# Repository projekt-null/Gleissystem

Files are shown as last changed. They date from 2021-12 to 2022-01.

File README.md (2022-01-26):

# Projekt-Null Spur 0 Gleise

Dieses GitHub Repository enthält Konstruktionsdateien zum Selbstbau von Spur 0 Gleismaterial. Die Konstruktionsdateien liegen sowohl im Ausgangsformat Autodesk Fusion 360 vor, als auch in diversen Exporten, um zum Beispiel Bauteile im Laserverfahren zu schneiden oder 3D zu drucken.

Weiterführende Informationen zu diesem Projekt sind der Projekt Null Homepage zu entnehmen: [Projekt Null Spur 0 Gleise](https://projekt-null.de/projekte/spur-0-gleise/einfuehrung/)

## Inhalt

- Regelspur_Gleise - Enthält Einzelschwellen oder Schwellenbänder für die Nachbildung von Holzschwellen im Modell
- Regelspur_Schablonen - Enthält Schablonen zum sauberen Verlegen von Einzelschwellen 

## Pushen von Änderungen

Zum heutigen Standpunkt ist noch unklar wie Änderungen, durch die Contributoren, ordentlich in das Repository übernommen werden können. Daher die Bitte, fügt den veränderten Dateien einen Suffix in Form von _vNNN_KKK hinzu. NNN steht dabei für eine laufende Versionsnummer und KKK für euer Namenskürzel. Sobald ihr dem Projekt beitritt, erhält ihr ein eindeutiges Namenskürzel.  

## Lizenzierung

Das Open Source Projekt *Projekt-Null Spur 0 Gleise* steht unter der LGLPv3 Lizenz. 

Über die bereitgestellten Konstruktionsdaten kann frei verfügt werden. Bei Vervielfältigung und kommerziellen Gebrauch, gilt es allerdings die Lizenzbedingungen einzuhalten. 

Mehr zur LGPLv3 Lizenz: https://www.gnu.org/licenses/lgpl-3.0.de.html

Alternativ wendet euch bei Fragen per E-Mail an: info@projekt-null.de

Ausgeschlossen von den Lizenzbedingungen

- alle Produkte vom Hersteller Hassler-Profile, Oberbühl 111, FL- 9487 Gamprin
- und das K-Modul-System.

Diese Liste gilt es allerdings zu aktualisieren, sobald weitere Produkte von Dritten in die Entwicklungen einfließen.

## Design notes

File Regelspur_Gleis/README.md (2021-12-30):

# Regelspur Gleis

Enthalten sind Konstruktionsdateien für Spur 0 Holzschwellen in Verbindung mit dem K-Modul-System Rippenplatten und den Abmessungen 58x5,8mm (entspr. der 2,6 Meter Schwelle). Die Abmessungen sind identisch mit den Holzschwellen von Michael Weinert und Hegob (Nachbildung in Kunstoff). Die Autodesk Fusion 360 Datei ist vollständig über Parameter veränderbar.

> **Achtung**: Die Schwellenbreite in den Zeichnungen beträgt aktuell 5,75mm, da beim Lasern die Breite größer als 5,8mm ausgefallen ist.

Die Laser-Cut Export stehen in zwei Ausführungen zur Verfügung:
- für Hegob Code 125 Schienenprofile
- für Hassler 3,5mm Schienenprofile

Durch die unterschiedlichen Breiten der Schienenprofile (Kopf und Fuß), muss die K-Modul-System Rippenplatte entsprechend positioniert werden, um die Spurweite von mind. 32mm exakt einzuhalten. In den Parametern wurde den Kopfbreiten sogar etwas Breite (0,05mm) hinzugegeben, was die Spurweite etwas vergrößert.

Hegob Schienenprofile sitzen allerdings nicht ganz so stramm in der K-Modul-System Rippenplatte, wie Hassler oder Peco Code 143 Schienenprofile. Für vorbildlichen Oberbau mit S49 Schienen (also Hegob Code 125) ist das System von Michael Weinert geeigneter.

Geeignetes Material für die Holzschwellen sind 3mm Eichen- oder Lindenvollholzplatten.

> **Achtung**: Das Schwellenband enthält unnötige Verfahrwege beim Laser-Cut. Eine verbesserte Variante befindet sich bereits in Arbeit.

## Inhalt
- 0_Schwellenband_Holz_K_Modul_System_v2.f3d - Autodesk Fusion 360 Konstruktionsdatei, über Parameter veränderbar
- 0_Schwellenband_Holz_K_Modul_System_v2.step - STEP Datei zum Importieren in andere 3D-Konstruktionsprogramme
- 0_Schwellenband_Holz_K_Modul_System_v2__Hegob_Laser_Cut_Kerf_0_15 - Export im DXF-Format zum Laserschneiden mit Schnittweite (Kerf-Width) von 0,15mm für Hegob Code 125 Schienenprofil
- 0_Schwellenband_Holz_K_Modul_System_v2__Hegob_Laser_Cut_Kerf_0_10 - Export im DXF-Format zum Laserschneiden mit Schnittweite (Kerf-Width) von 0,10mm für Hegob Code 125 Schienenprofil
- 0_Einzelschwelle_Holz_K_Modul_System_v2__Hegob_Laser_Cut_Kerf_0_15 - Export im DXF-Format zum Laserschneiden mit Schnittweite (Kerf-Width) von 0,15mm für Hegob Code 125 Schienenprofil
- 0_Einzelschwelle_Holz_K_Modul_System_v2__Hegob_Laser_Cut_Kerf_0_10 - Export im DXF-Format zum Laserschneiden mit Schnittweite (Kerf-Width) von 0,10mm für Hegob Code 125 Schienenprofil
- 0_Schwellenband_Holz_K_Modul_System_v2__Hassler_Laser_Cut_Kerf_0_15 - Export im DXF-Format zum Laserschneiden mit Schnittweite (Kerf-Width) von 0,15mm für Hassler 3,5mm Schienenprofil
- 0_Schwellenband_Holz_K_Modul_System_v2__Hassler_Laser_Cut_Kerf_0_10 - Export im DXF-Format zum Laserschneiden mit Schnittweite (Kerf-Width) von 0,10mm für Hassler 3,5mm Schienenprofil
- 0_Einzelschwelle_Holz_K_Modul_System_v2__Hassler_Laser_Cut_Kerf_0_15 - Export im DXF-Format zum Laserschneiden mit Schnittweite (Kerf-Width) von 0,15mm für Hassler 3,5mm Schienenprofil
- 0_Einzelschwelle_Holz_K_Modul_System_v2__Hassler_Laser_Cut_Kerf_0_10 - Export im DXF-Format zum Laserschneiden mit Schnittweite (Kerf-Width) von 0,10mm für Hassler 3,5mm Schienenprofil

## Offene Punkte

- Unterstützung for Peco Code 143 Schienenprofil hinzufügen
- Laser-Cut Verfahrwege optimieren
- CNC Fräsdatei mit Angabe des Fräserdurchmessers hinzufügen (max. 1,5mm!)

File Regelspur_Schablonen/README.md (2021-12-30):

# Regelspur Schablonen

Enthalten sind Konstruktionsdateien für Schablonen zum Verlegen von Spur 0 Einzelschwellen (58x5,8mm) gemäß Eisenbahner Richtlinien, akuell

- 15m Joche mit Schwelleneinteilung nach DRG-Richtlinie

Geeignetes Material zum Laserschneiden sind 1mm Finnpappe oder MDF.

Die Schablonen können wahlweise auf dem Trassen-/Schotterbett verbleiben oder werden wieder entnommen. Die Schablonen können auch mehrfach verwendet werden. 

Laut FREMO Spur 0 Norm, lautet die aktuelle Trassen-/Schotterbreite 68mm.

## Inhalt

- 0_15m_Joch_Gerade_Schablone_v7.f3d - Autodesk Fusion 360 Konstruktionsdatei, über Parameter veränderbar, u.a. Trassen-/Schotterbett-Breite
- 0_15m_Joch_Gerade_Schablone_v7.step - STEP Datei zum Importieren in andere 3D-Konstruktionsprogramme
- 0_15m_Joch_Gerade_Schablone_v7__Laser_Cut_Kerf_0_10.dxf - Export im DXF-Format zum Laserschneiden mit Schnittweite (Kerf-Width) von 0,10mm
- 0_15m_Joch_Gerade_Schablone_v7__Laser_Cut_Kerf_0_15.dxf - Export im DXF-Format zum Laserschneiden mit Schnittweite (Kerf-Width) von 0,15mm
- 0_15m_Joch_Gebogene_Schablone_v8.f3d - Autodesk Fusion 360 Konstruktionsdatei, über Parameter veränderbar, u.a. Trassen-/Schotterbett-Breite und Bogen-Radius
- 0_15m_Joch_Gebogene_Schablone_v8.step - STEP Datei zum Importieren in andere 3D-Konstruktionsprogramme
- 0_15m_Joch_Gebogene_Schablone_v8__R2500mm_Laser_Cut_Kerf_0_10.dxf - Export im DXF-Format zum Laserschneiden mit Radius 2500mm und Schnittweite (Kerf-Width) von 0,10mm
- 0_15m_Joch_Gebogene_Schablone_v8__R2500mm_Laser_Cut_Kerf_0_15.dxf - Export im DXF-Format zum Laserschneiden mit Radius 2500mm und Schnittweite (Kerf-Width) von 0,15mm
- 0_15m_Joch_Gebogene_Schablone_v8__Lenz_R10_Laser_Cut_Kerf_0_10.dxf - Export im DXF-Format zum Laserschneiden mit Radius Lenz R10 (1649,39mm) und Schnittweite (Kerf-Width) von 0,10mm
- 0_15m_Joch_Gebogene_Schablone_v8__Lenz_R10_Laser_Cut_Kerf_0_15.dxf - Export im DXF-Format zum Laserschneiden mit Radius Lenz R10 (1649,39mm) und Schnittweite (Kerf-Width) von 0,15mm

## Offene Punkte

- 30m Joche gemäß DRG-Richtlinien
- 30m Joche gemäß späterer DB Vorgaben
- Laser Cut Exporte mit weiteren Bogen Radien, zum Beispiel 4000mm, 4222mm, etc.
- Trennstelle zwischen den Schnwellen hinzufügen, damit die Schablone bei einmalige Verwendung, nach links und rechts rausgezogen werden.

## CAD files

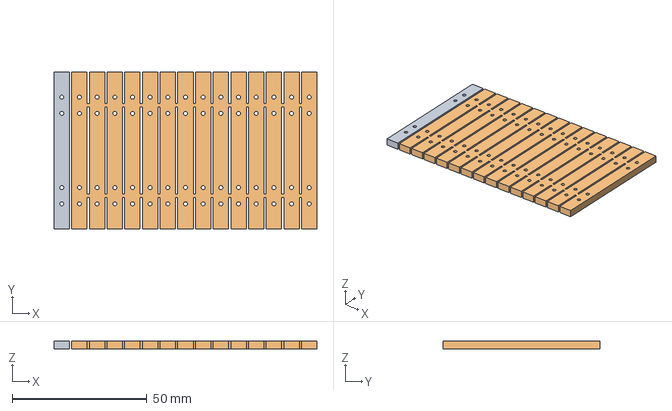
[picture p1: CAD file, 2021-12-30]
Regelspur_Gleis/0_Schwellenband_Holz_K_Modul_System_v2.step
97.5 x 58.0 x 3.00 mm

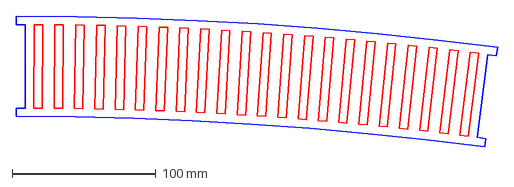
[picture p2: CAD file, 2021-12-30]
Regelspur_Schablonen/0_15m_Joch_Gebogen_Schablone_v8__R2500mm_Laser_Cut_Kerf_0_15.dxf
334.3 x 90.8 mm

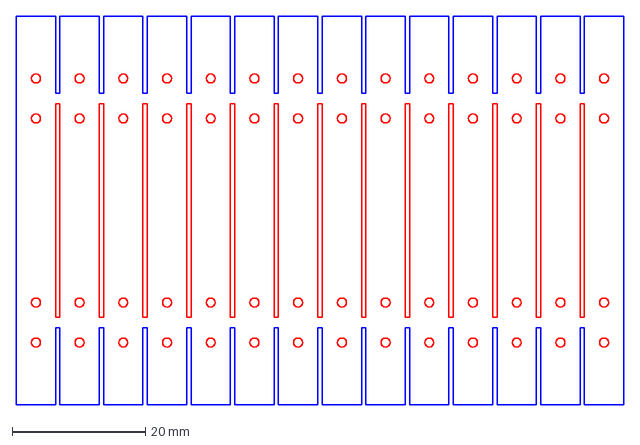
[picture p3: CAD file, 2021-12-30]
Regelspur_Gleis/0_Schwellenband_Holz_K_Modul_System_v2__Hassler_Laser_Cut_Kerf_0_15.dxf
91.1 x 58.2 mm

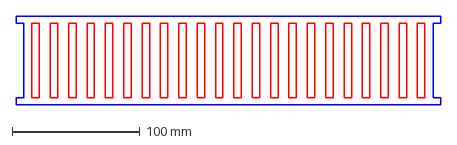
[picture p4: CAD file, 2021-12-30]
Regelspur_Schablonen/0_15m_Joch_Gerade_Schablone_v7__Laser_Cut_Kerf_0_15.dxf
332.8 x 69.7 mm

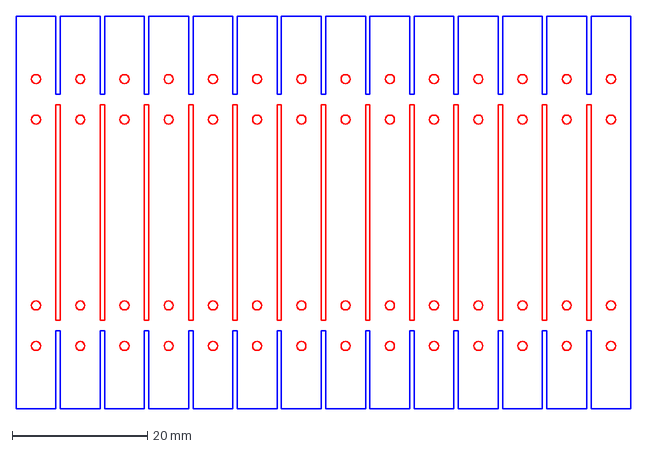
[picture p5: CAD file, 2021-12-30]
Regelspur_Gleis/0_Schwellenband_Holz_K_Modul_System_v2__Hegob_Laser_Cut_Kerf_0_15.dxf
91.1 x 58.2 mm

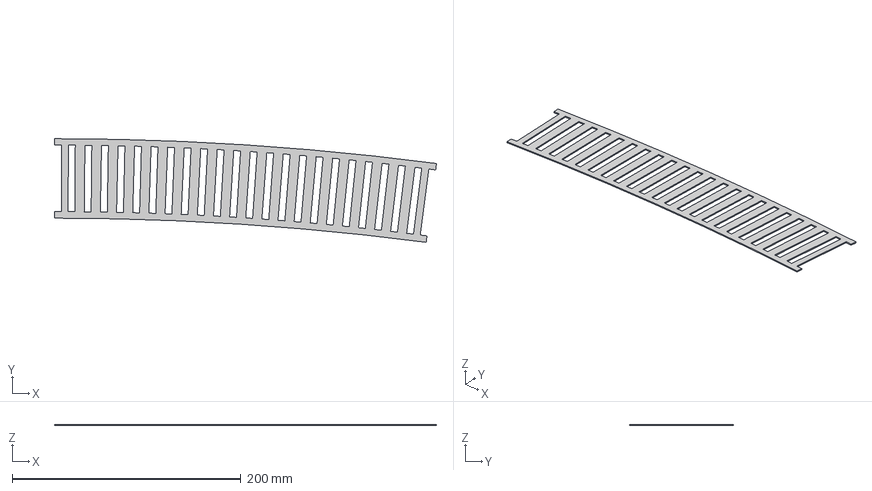
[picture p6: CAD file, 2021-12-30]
Regelspur_Schablonen/0_15m_Joch_Gebogen_Schablone_v8.step
334.2 x 90.7 x 1.00 mm

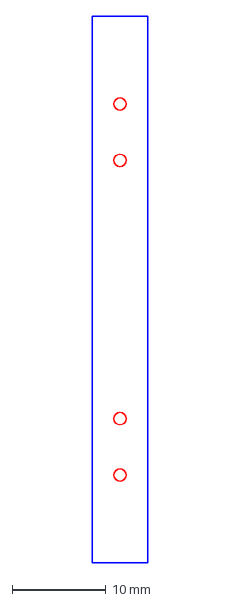
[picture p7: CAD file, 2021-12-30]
Regelspur_Gleis/0_Einzelschwelle_Holz_K_Modul_System_v2__Hegob_Laser_Cut_Kerf_0_15.dxf
5.90 x 58.2 mm

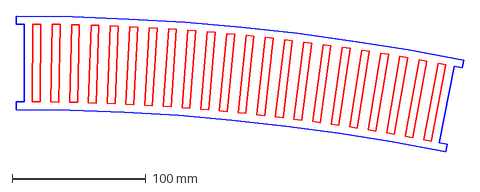
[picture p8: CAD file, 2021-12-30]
Regelspur_Schablonen/0_15m_Joch_Gebogen_Schablone_v8__Lenz_R10_Laser_Cut_Kerf_0_15.dxf
334.4 x 101.3 mm

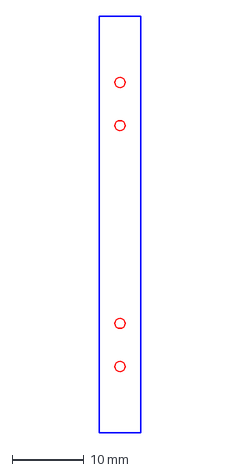
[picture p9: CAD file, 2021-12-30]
Regelspur_Gleis/0_Einzelschwelle_Holz_K_Modul_System_v2__Hassler_Laser_Cut_Kerf_0_10.dxf
5.85 x 58.1 mm

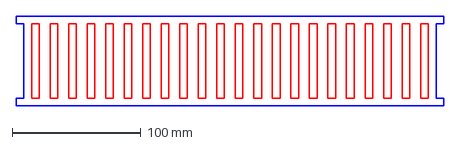
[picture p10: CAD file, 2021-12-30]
Regelspur_Schablonen/0_15m_Joch_Gerade_Schablone_v7__Laser_Cut_Kerf_0_10.dxf
332.8 x 69.6 mm

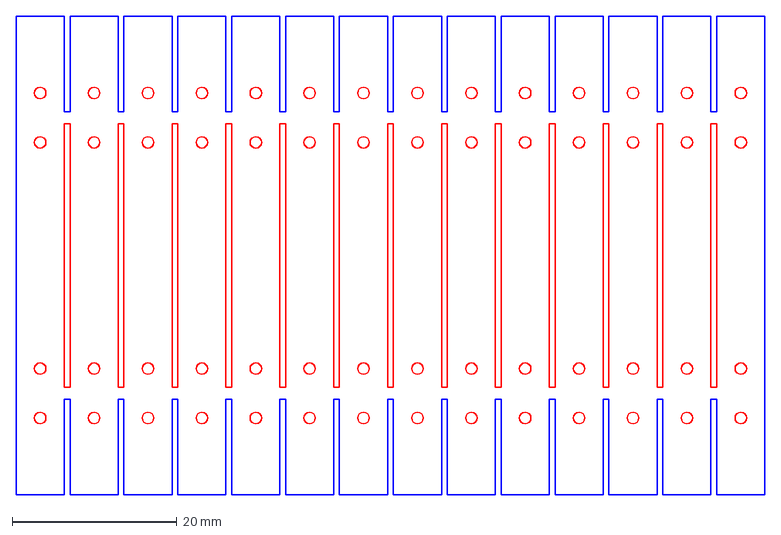
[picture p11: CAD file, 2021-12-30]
Regelspur_Gleis/0_Schwellenband_Holz_K_Modul_System_v2__Hegob_Laser_Cut_Kerf_0_10.dxf
91.0 x 58.1 mm

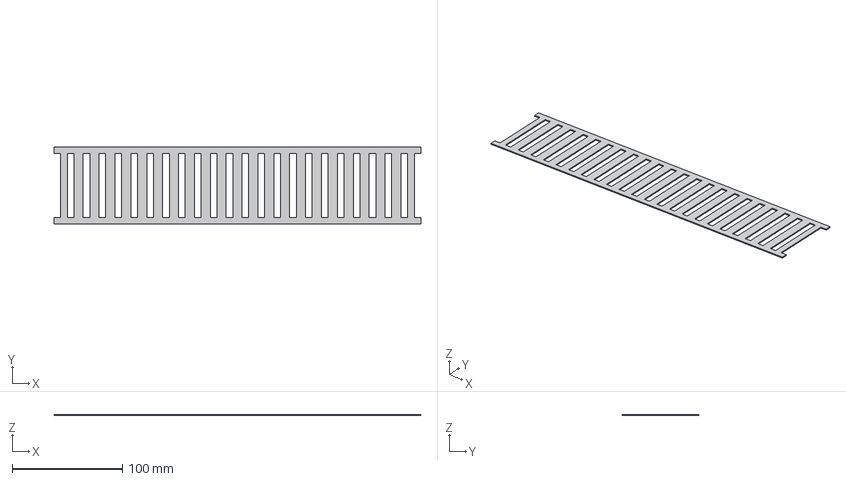
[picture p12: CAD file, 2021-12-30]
Regelspur_Schablonen/0_15m_Joch_Gerade_Schablone_v7.step
332.7 x 69.5 x 1.00 mm

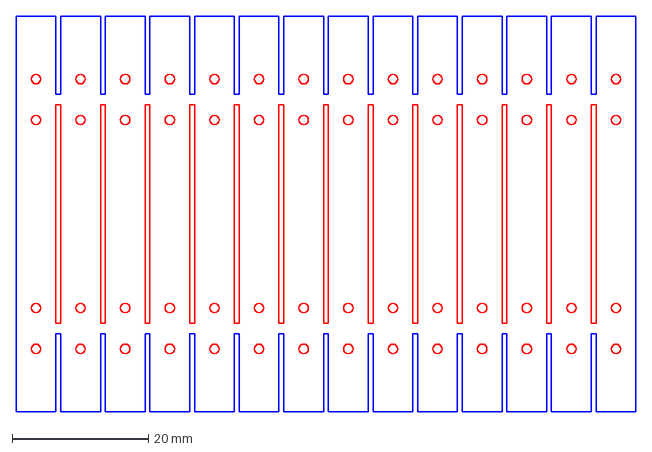
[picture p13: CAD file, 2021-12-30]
Regelspur_Gleis/0_Schwellenband_Holz_K_Modul_System_v2__Hassler_Laser_Cut_Kerf_0_10.dxf
91.0 x 58.1 mm

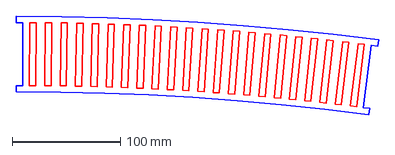
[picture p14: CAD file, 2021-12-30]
Regelspur_Schablonen/0_15m_Joch_Gebogen_Schablone_v8__R2500mm_Laser_Cut_Kerf_0_10.dxf
334.3 x 90.8 mm

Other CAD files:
Regelspur_Gleis/0_Einzelschwelle_Holz_K_Modul_System_v2__Hassler_Laser_Cut_Kerf_0_15.dxf
Regelspur_Schablonen/0_15m_Joch_Gebogen_Schablone_v8__Lenz_R10_Laser_Cut_Kerf_0_10.dxf
Regelspur_Gleis/0_Einzelschwelle_Holz_K_Modul_System_v2__Hegob_Laser_Cut_Kerf_0_10.dxf
Regelspur_Schablonen/0_15m_Joch_Gebogen_Lenz_R10_Schablone_LaserCut_Kerf_0_15mm.dxf
Regelspur_Gleis/0_Schwellenband_Holz_K_Modul_System_v2.f3d
Regelspur_Schablonen/0_15m_Joch_Gebogen_2500mm_Schablone_LaserCut_Kerf_0_10mm.dxf
Regelspur_Schablonen/0_15m_Joch_Gebogen_2500mm_Schablone_LaserCut_Kerf_0mm.dxf
Regelspur_Schablonen/0_15m_Joch_Gebogen_Lenz_R10_Schablone_LaserCut_Kerf_0_10mm.dxf
Regelspur_Schablonen/0_15m_Joch_Gebogen_Schablone_v8.f3d
Regelspur_Schablonen/0_15m_Joch_Gerade_Schablone_LaserCut_Kerf_0_10mm.dxf
Regelspur_Schablonen/0_15m_Joch_Gerade_Schablone_LaserCut_Kerf_0mm.dxf
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

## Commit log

2021-12-23 Schablonen für Lenz R10 und 2500mm hinzugefügt.
    [0_15m_Joch_Gebogen_2500mm_Schablone_LaserCut_Kerf_0_10mm.dxf, 0_15m_Joch_Gebogen_2500mm_Schablone_LaserCut_Kerf_0_15mm.dxf, 0_15m_Joch_Gebogen_2500mm_Schablone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]
2021-12-23 Meterspur Entwicklung hinzugefügt.
    [0_15m_Joch_Gebogen_2500mm_Schablone_LaserCut_Kerf_0_10mm.dxf, 0_15m_Joch_Gebogen_2500mm_Schablone_LaserCut_Kerf_0_15mm.dxf, 0_15m_Joch_Gebogen_2500mm_Schablone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]
2021-12-29 Vorschau zur EW 100 1:6,6 Weiche hinzugefügt
    [EW_100_1_6_6_Spur_0_v81.step]
2021-12-30 Schablonen aktualisiert, Holzschwellen hinzugefügt
    [0_15m_Joch_Gebogen_2500mm_Schablone_LaserCut_Kerf_0_15mm.dxf, 0_15m_Joch_Gebogen_Lenz_R10_Schablone_LaserCut_Kerf_0mm.dxf, 0_15m_Joch_Gebogen_Schablone.f3d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]
